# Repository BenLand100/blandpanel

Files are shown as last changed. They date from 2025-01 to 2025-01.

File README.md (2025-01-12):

# BLandPanel

This aims to be a reference design for a DYI telescope automated flat panel.
Any RP2040 dev board, or similar device, capable of running MicroPython,
a PWM modulated servo, and some commodity electronics components make up the
electronics. Some Python and C++ for writing the firmware and software driver
(respectively - which is quite ironic) to allow INDI capable clients to control
the device and a bit of CAD and 3D printing to hold it all together.

The flat panel ~~and CAD itself are~~ is TBD.

## RP2040 Firmware

Firmware for the RP2040 microcontroller is available in `rpico-firmare`.

Any RP2040 dev board with some reasonable pinout will work. This repo is tested
and configured for the vanilla Raspberry Pi Pico using some arbitrary GPIO and 
one optional-ish ADC pin. A small current driver for the LED panel will be 
required. 

## INDI driver

A driver based heavily off the reference INDI driver that can control the 
firmware is available in `indi-driver`.

## ASCOM driver

The firmware also impelemnts (untested) the flat panel serial protocol found in 
[DarkSkyGeek's ascom-flat-panel repo](https://github.com/jlecomte/ascom-flat-panel/)
so the ASCOM driver found there would very likely control this firmware fine.

## CAD Design

There is a FreeCAD project in the `design` directory along with exported models
of the current build. This is very much a WIP and the current model is a test 
design primarily to figure out what needs to be changed for the next revision.

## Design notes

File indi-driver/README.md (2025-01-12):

# BLandPanel INDI driver

For now, only implements the nost basic functionality.

```sh
mkdir build
cd build
cmake -DCMAKE_INSTALL_PREFIX=/usr -DCMAKE_BUILD_TYPE=Debug ../
make
sudo make install
```

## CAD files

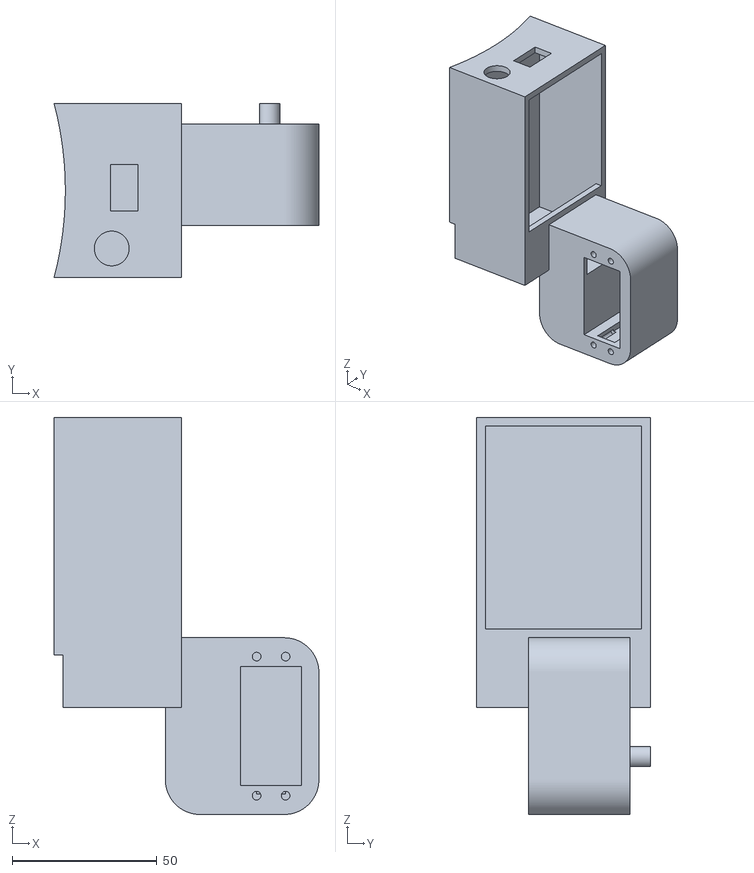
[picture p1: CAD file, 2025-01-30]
design/BlandPanel-FittedAssembly.stl
91.4 x 60.0 x 137.0

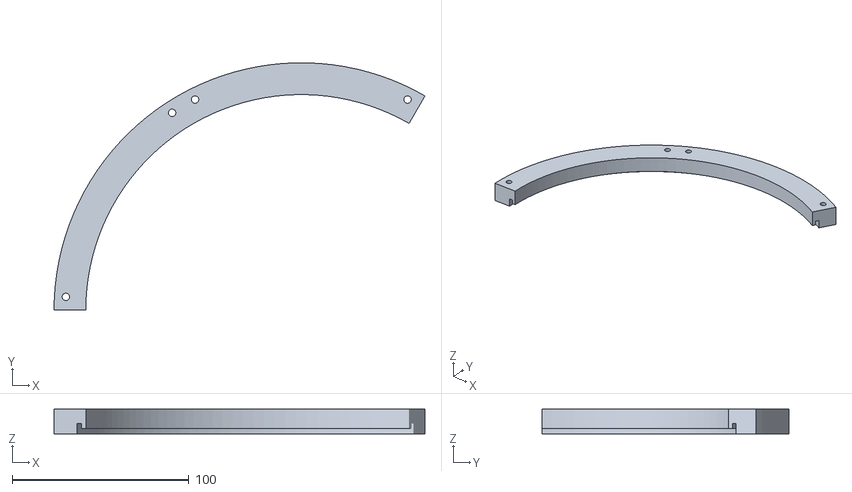
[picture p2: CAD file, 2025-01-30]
design/BlandPanel-BottomRim1.stl
210.0 x 140.0 x 14.0

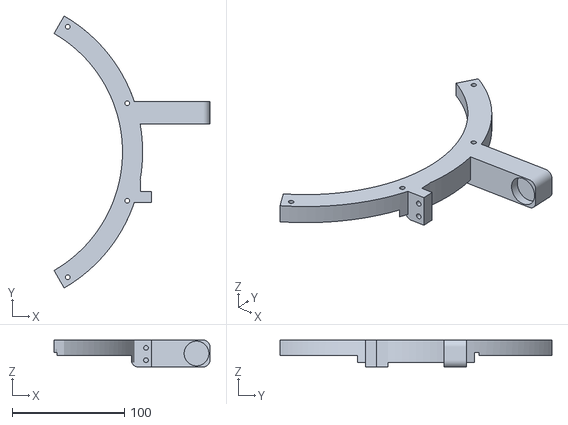
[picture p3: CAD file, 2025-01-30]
design/BlandPanel-Base.stl
139.0 x 242.5 x 24.0

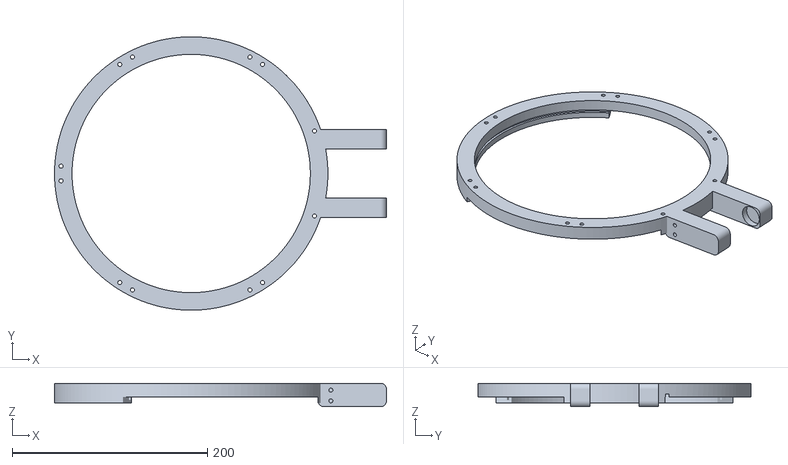
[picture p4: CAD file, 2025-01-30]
design/BlandPanel-MountablePanel.stl
340.0 x 279.9 x 24.0

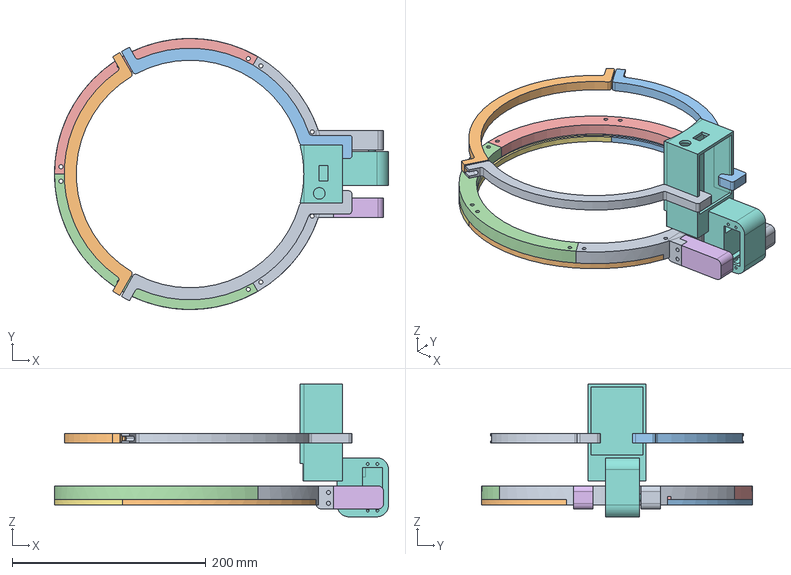
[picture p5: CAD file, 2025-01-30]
design/BlandPanel.FCStd
345.0 x 280.0 x 137.0 mm
Base
TopRim2
TopRim1
BottomRim2
BottomRim1
DriveArm
TopRim3
HousingAssembly
SideFGrabber1
SideFGrabber2
BackFGrabber

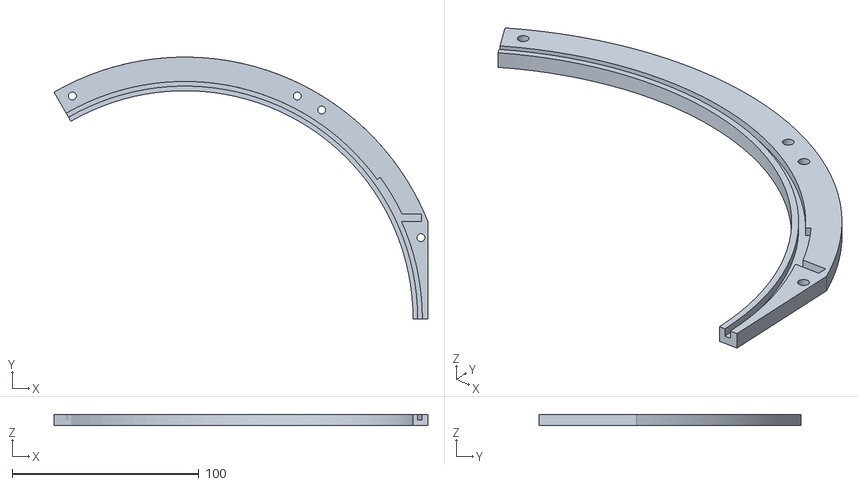
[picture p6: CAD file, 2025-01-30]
design/BlandPanel-TopRim1.stl
200.0 x 140.0 x 6.00

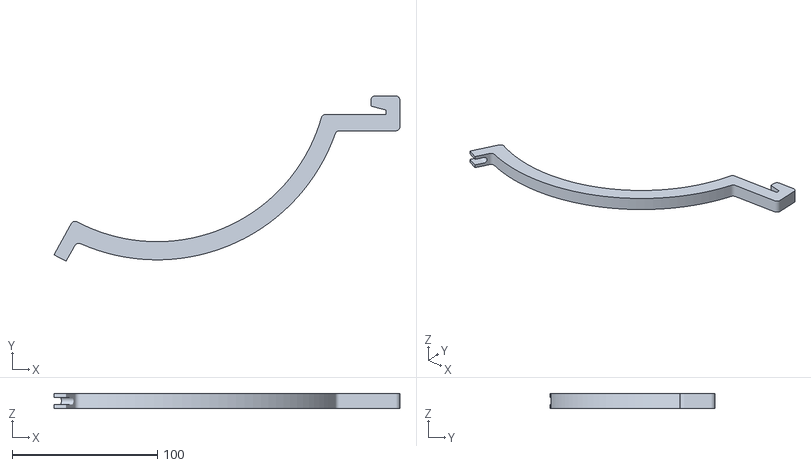
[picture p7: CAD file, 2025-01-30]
design/BlandPanel-SideGrabber.stl
237.9 x 113.6 x 10.0

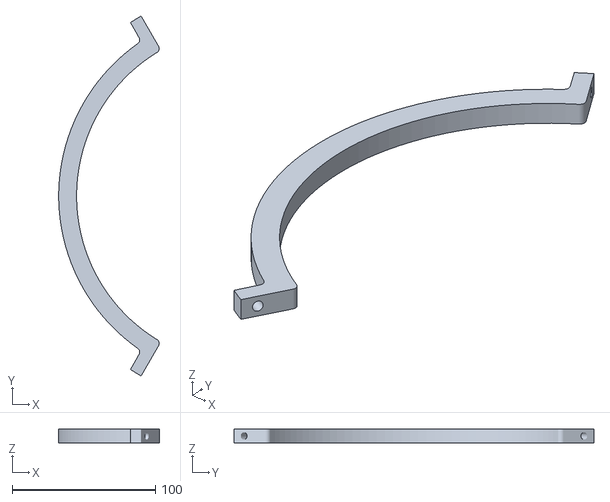
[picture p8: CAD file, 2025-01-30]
design/BlandPanel-BackGrabber.stl
70.1 x 251.1 x 10.0

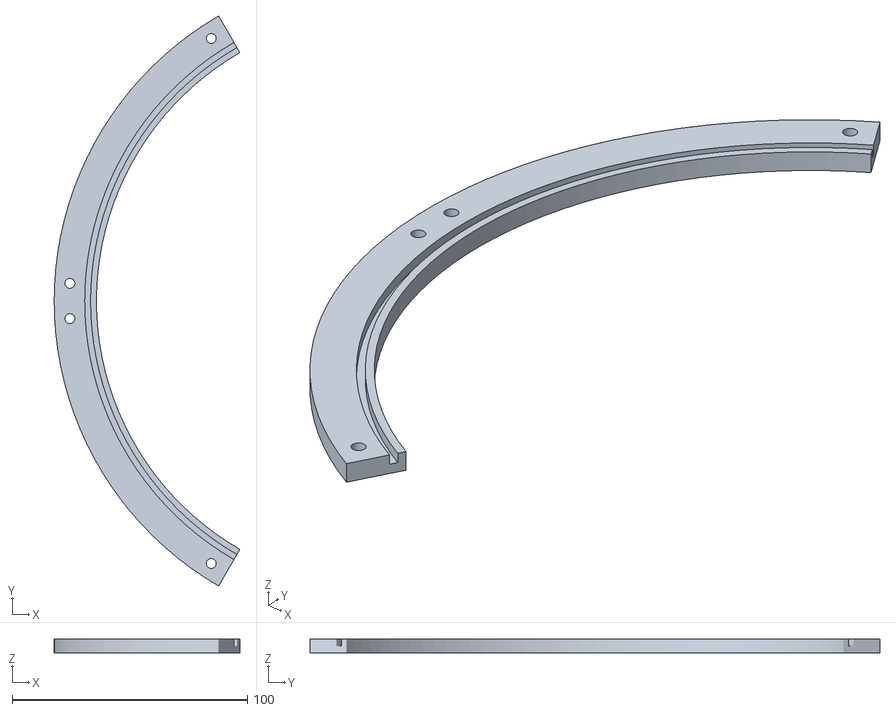
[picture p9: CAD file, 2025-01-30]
design/BlandPanel-TopRim3.stl
79.0 x 242.5 x 6.00

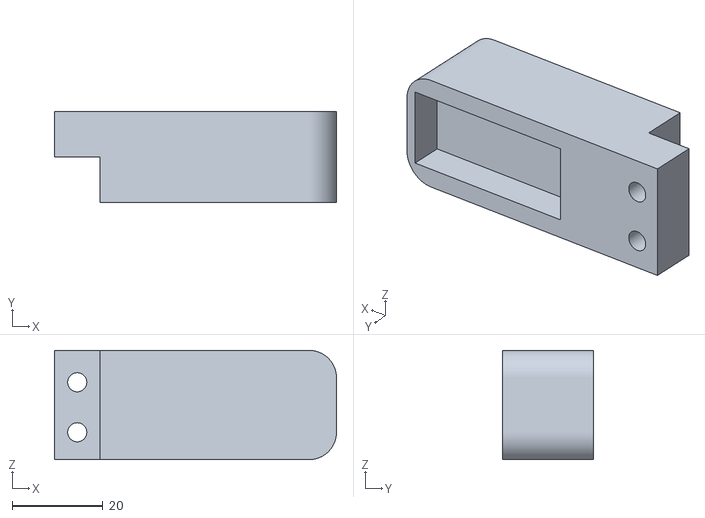
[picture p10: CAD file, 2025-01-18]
design/BlandPanel-DriveArm.stl
62.0 x 20.0 x 24.0

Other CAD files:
design/BlandPanel-BottomRim2.stl
design/BlandPanel-TopRim2.stl

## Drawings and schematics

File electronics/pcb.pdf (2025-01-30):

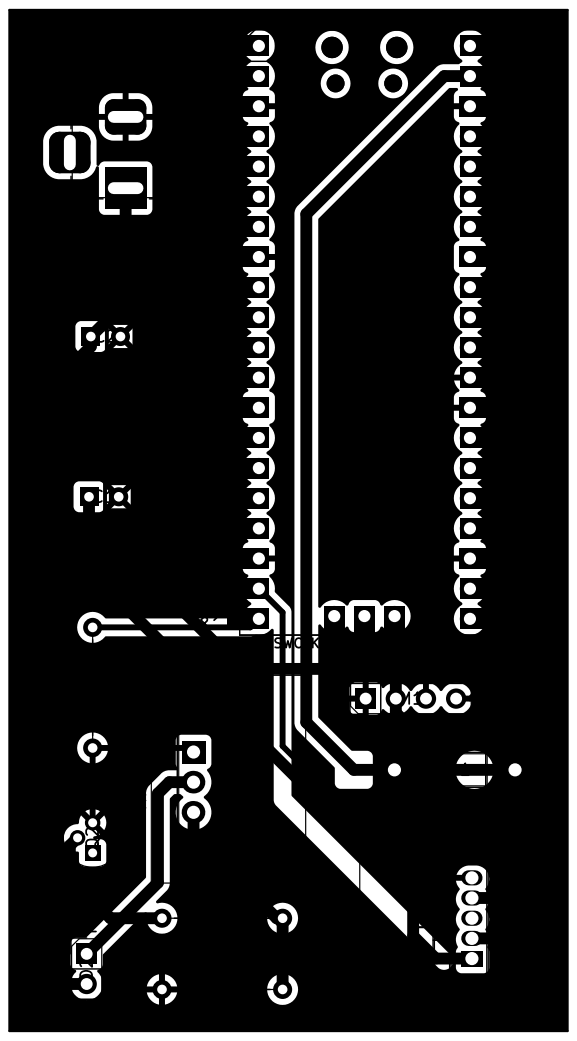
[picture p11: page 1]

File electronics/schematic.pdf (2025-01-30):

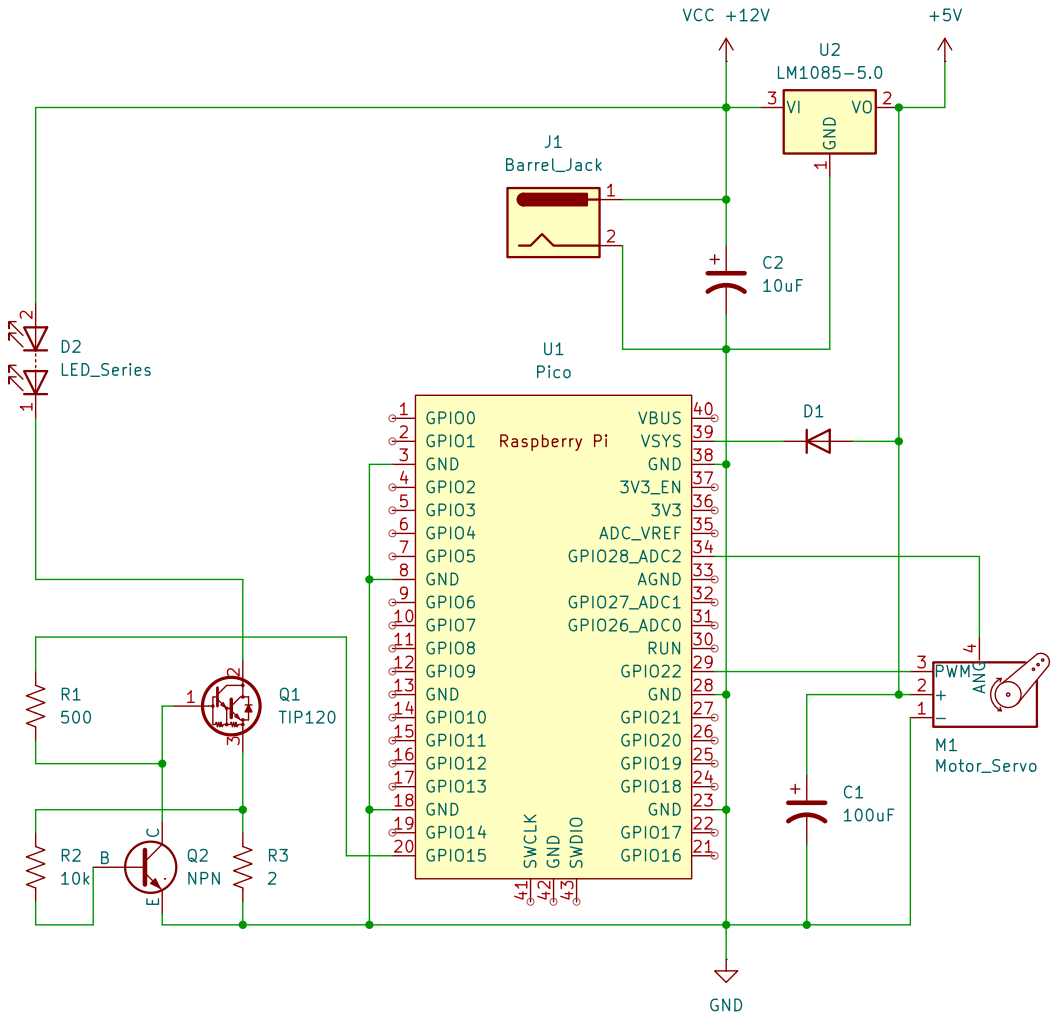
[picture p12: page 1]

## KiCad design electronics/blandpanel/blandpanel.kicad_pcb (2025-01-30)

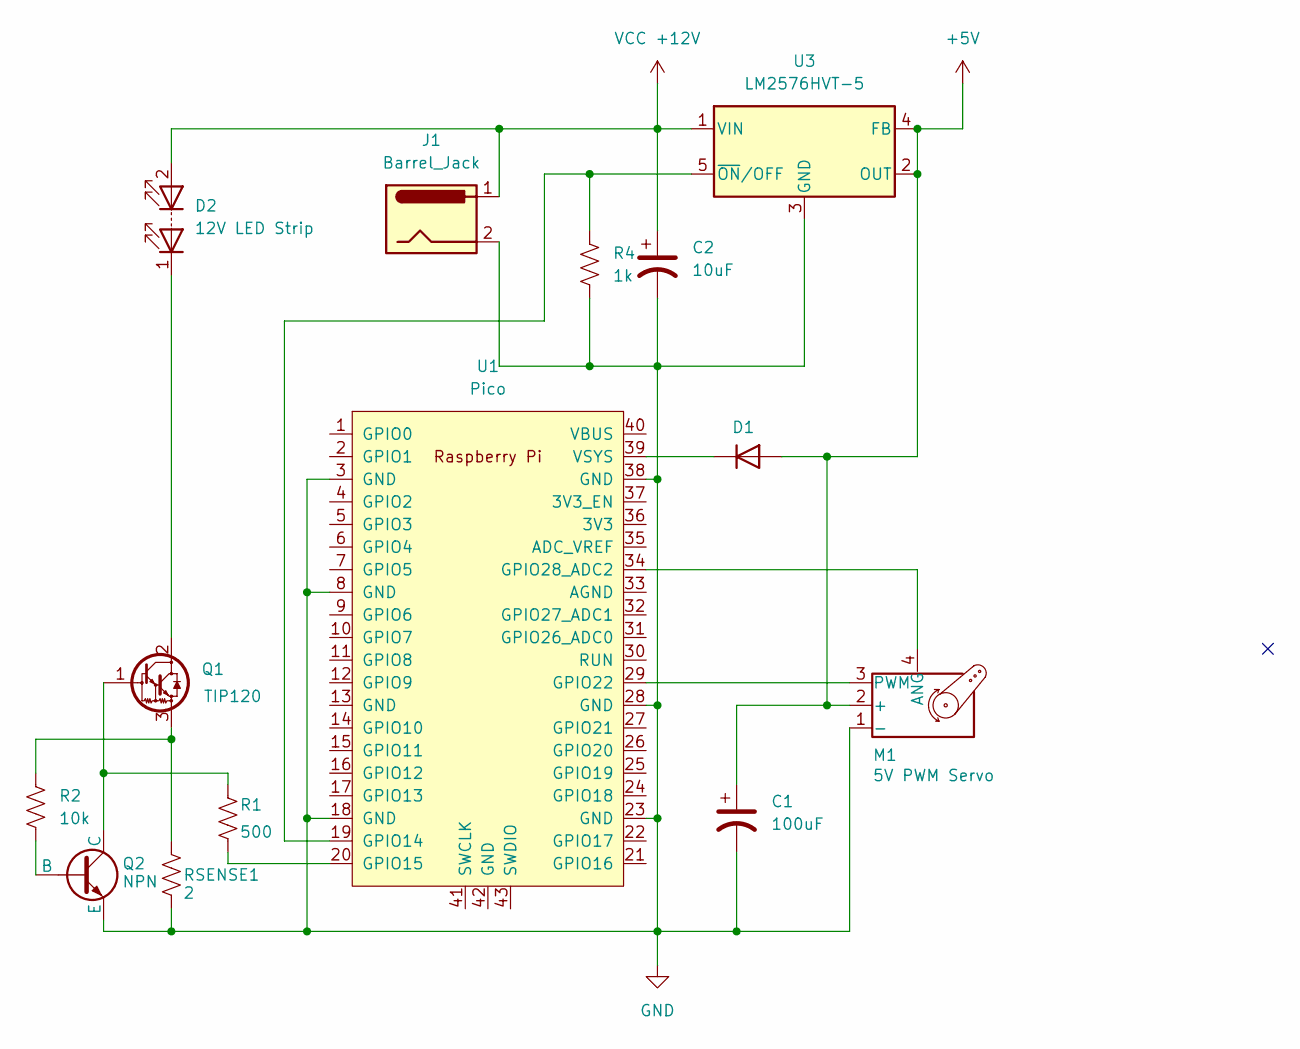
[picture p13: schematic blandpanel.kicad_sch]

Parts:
C1: 100uF; CP_Radial_D8.0mm_P2.50mm
C2: 10uF; CP_Radial_D8.0mm_P2.50mm
D1: 40V; D_DO-41_SOD81_P10.16mm_Horizontal
D2: 12V LED Strip; PinHeader_1x02_P2.54mm_Vertical
J1: Barrel_Jack; BarrelJack_Horizontal
M1: 5V PWM Servo; PinHeader_1x04_P2.54mm_Vertical
Q1: TIP120; TO-220-3_Vertical
Q2: NPN; TO-92
R1: 500; R_Axial_DIN0207_L6.3mm_D2.5mm_P10.16mm_Horizontal
R2: 10k; R_Axial_DIN0207_L6.3mm_D2.5mm_P10.16mm_Horizontal
R4: 1k
RSENSE1: 2; R_Axial_DIN0207_L6.3mm_D2.5mm_P10.16mm_Horizontal
U1: Pico; RPi_Pico_SMD_TH
U3: LM2576HVT-5; TO-220-5_Vertical

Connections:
+5V: C1.1, D1.2 (A), M1.2 (+), U3.2 (OUT), U3.4 (FB)
GND: C1.2, C2.2, J1.2, M1.1 (-), Q2.3 (E), R4.2, RSENSE1.2, U1.3 (GND), U1.8 (GND), U1.18 (GND), U1.23 (GND), U1.28 (GND), U1.38 (GND), U3.3 (GND)
unnamed: D1.1 (K), U1.39 (VSYS)
unnamed: D2.1 (K), Q1.2 (C)
unnamed: M1.4 (ANG), U1.34 (GPIO28_ADC2)
unnamed: M1.3 (PWM), U1.29 (GPIO22)
unnamed: Q1.1 (B), Q2.1 (C), R1.1
unnamed: Q1.3 (E), R2.1, RSENSE1.1
unnamed: Q2.2 (B), R2.2
unnamed: R4.1, U1.19 (GPIO14), U3.5 (~ON/OFF)
unnamed: R1.2, U1.20 (GPIO15)
VCC +12V: C2.1, D2.2 (A), J1.1, U3.1 (VIN)

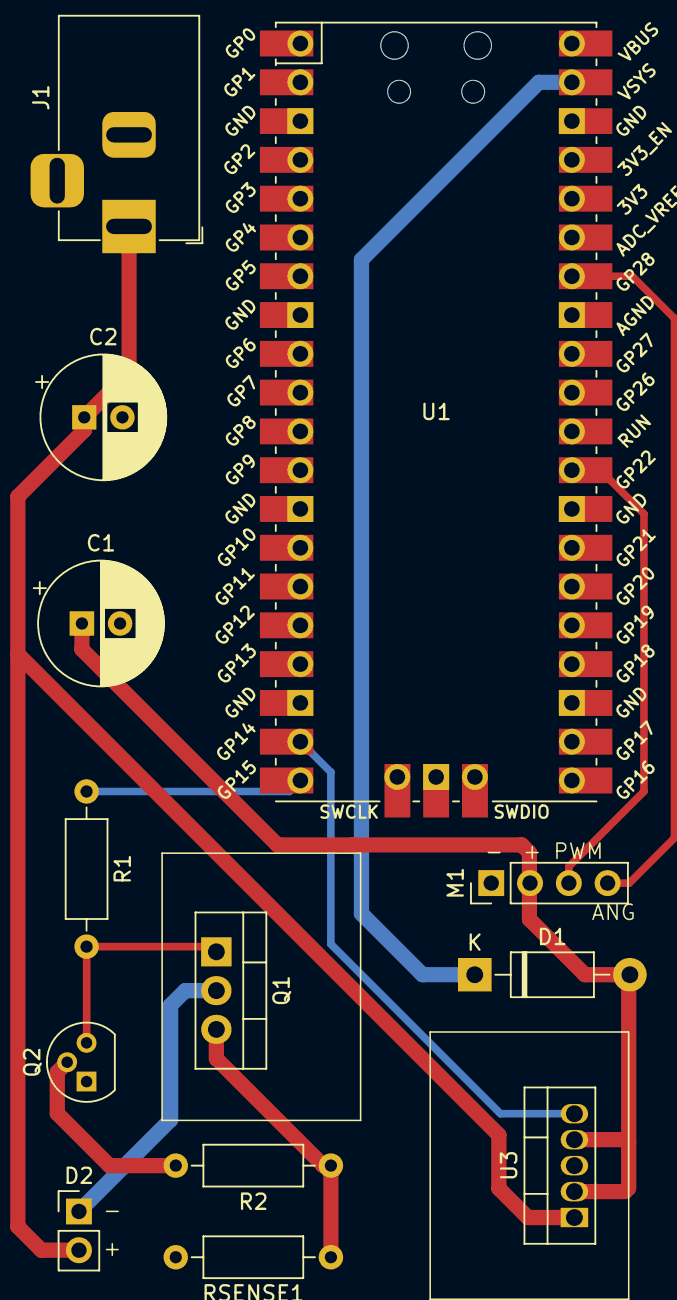
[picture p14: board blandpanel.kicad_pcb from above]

Board: 2 copper layers, 13 parts (0 on the bottom side), 12 nets.

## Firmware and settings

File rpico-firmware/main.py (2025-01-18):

import machine
import time
import sys
from machine import SoftI2C, SoftSPI, PWM, ADC, Pin

# Power LED
led = Pin(25, Pin.OUT)
led.value(1)

# PWM for flat panel
panel = PWM(Pin(15))
panel.freq(10000)
panel.duty_ns(0)

# 5V from 12V regulator (for servo & pico)
en_5v = Pin(14, Pin.OUT)
en_5v.value(0)

# PWM servo 500us - 2500us pulse range (make configurable?)
servo = PWM(Pin(22))
servo.duty_ns(0) #Servo will ignore
servo.freq(100)

# Turn on Servo and 5V bus
en_5v.value(1)

# Analog value proportional to servo angle (optional)
angle_adc = ADC(2)

# TODO save in flash?
PULSE_ZERO = -0.026
PULSE_270 = 0.951
ADC_ZERO = 60850.8
ADC_270 = 6985.0
GUID = 'some-kind-of-unique-identifier'
DEFAULT_BRIGHTNESS = 0.75
ANGLE_TOLERANCE = 10.0
OPENED_ANGLE = 270.0
CLOSED_ANGLE = 0.0

def set_angle(angle, calibrating=False, wait=2):
    if not calibrating:
        assert angle >= -20 and angle <= 290, 'Angle out of bounds'
        angle = (angle / 270)*(PULSE_270-PULSE_ZERO)+PULSE_ZERO
    servo.duty_ns(int(500e3+angle*2e6))
    time.sleep(wait)
    
def get_angle(average=10, calibrating=False):
    avg = sum([angle_adc.read_u16() for i in range(average)])/average
    if calibrating:
        return avg
    else:
        return (avg-ADC_ZERO)*270/(ADC_270-ADC_ZERO)
    
def get_state():
    angle = get_angle()
    if abs(angle-CLOSED_ANGLE) < ANGLE_TOLERANCE:
        return 'closed'
    elif abs(angle-OPENED_ANGLE) < ANGLE_TOLERANCE:
        return 'opened'
    else:
        return 'intermediate'
    
def set_state(state):
    now = get_state()
    if state == 'opened':        
        if now != 'opened':
            set_angle(OPENED_ANGLE)
    elif state == 'closed':
        if now != 'closed':
            set_angle(CLOSED_ANGLE)
    else:
        raise Exception(f'Invalid state {state}')

ENABLED = False
BRIGHTNESS = DEFAULT_BRIGHTNESS

def set_enabled(enabled=True):
    global ENABLED
    if enabled:
        panel.duty_u16(int(BRIGHTNESS*(2**16-1)))
        ENABLED = True
    else:
        panel.duty_u16(0)
        ENABLED = False
    
def get_enabled(enabled=True):
    return ENABLED

def set_brightness(brightness):
    global BRIGHTNESS
    assert brightness >= 0 and brightness <= 1.0, 'Brightness out of bounds'
    BRIGHTNESS = brightness
    if ENABLED:
        panel.duty_u16(int(BRIGHTNESS*(2**16-1)))

def get_brightness():
    return BRIGHTNESS

ESTOP = False
def estop():
    global ESTOP
    en_5v.value(0)
    ESTOP = True
    
def allclear():
    global ESTOP
    if ESTOP:
        ESTOP = False
        en_5v.value(1)
        
while True:
    cmd = sys.stdin.readline().upper().strip()
    try:
        if len(cmd) < 2:
            continue
        elif cmd.startswith('ESTOP'):
            estop()
            print('ESTOP: ALLCLEAR REQUIRED TO RESUME MOTION')
        elif cmd.startswith('ALLCLEAR'):
            allclear()
            print('OK')
        elif cmd.startswith('COMMAND:'): # Using this ASCOM driver https://github.com/jlecomte/ascom-flat-panel/
            if cmd == 'COMMAND:PING':
                print(f'RESULT:PING:OK:{GUID}')
            elif cmd == 'COMMAND:INFO':
                print('RESULT:INFO:BLandPanel v0')
            elif cmd == 'COMMAND:CALIBRATOR:GETBRIGHTNESS':
                print('RESULT:CALIBRATOR:BRIGHTNESS:{BRIGHTNESS}')
            elif cmd.startswith('COMMAND:CALIBRATOR:BRIGHTNESS:'):
                parts = cmd.split(':')
                if len(parts) > 3:
                    value = float(parts[3])
                    set_brightness(value)
            elif cmd.startswith('COMMAND:CALIBRATOR:ON'):
                set_state('closed')
                parts = cmd.split(':')
                if len(parts) > 3:
                    value = float(parts[3])
                    set_brightness(value)
                else:
                    set_brightness(DEFAULT_BRIGHTNESS)
            elif cmd == 'COMMAND:CALIBRATOR:OFF':
                set_enabled(False)
                set_state('opened')
            else:
                print('ERROR:INVALID_COMMAND')
        elif cmd == 'REPL':
            print('GOODBYE')
            break
        elif cmd == 'RESET':
            print('GOODBYE')
            machine.reset() #exits
        elif cmd == 'STATUS':
            print(f'OK STATE: {get_state().upper()} BRIGHTNESS: {get_brightness():0.2f} ENABLED: {str(get_enabled()).upper()}')
        elif cmd.startswith('ON'):
            parts = cmd.split(' ')
            if len(parts) > 1:
                value = float(parts[1])
                set_brightness(value)
            set_enabled(True)
            print('OK')
        elif cmd == 'OFF':
            set_enabled(False)
            print('OK')
        elif cmd.startswith('BRIGHT'):
            parts = cmd.split(' ')
            if len(parts) > 1:
                value = float(parts[1])
                set_brightness(value)
                print('OK')
            else:
                print(f'{get_brightness():0.2f}')
        elif cmd == 'OPEN':
            set_state('opened')
            if get_state() == 'opened':
                print('OK')
            else:
                print('FAIL')
        elif cmd == 'CLOSE':
            set_state('closed')
            if get_state() == 'closed':
                print('OK')
            else:
                print('FAIL')
        elif cmd.startswith('STATE'):
            parts = cmd.split(' ')
            if len(parts) > 1:
                state = parts[1].lower()
                set_state(state)
                if get_state() == state:
                    print('OK')
                else:
                    print('FAIL')
            else:
                print(get_state().upper())
        elif cmd.startswith('ANGLE'):
            parts = cmd.split(' ')
            if len(parts) > 1:
                value = float(parts[1])
                set_angle(value)
                angle = get_angle()
                if abs(angle-value) < ANGLE_TOLERANCE:
                    print('OK')
                else:
                    print('FAIL')
            else:
                angle = get_angle()
                print(f'{angle}')
        else:
            print(f'Useful Commands: STATUS, STATE [open|closed], ON [0-1], BRIGHT [0-1], OFF, OPEN, CLOSE, ANGLE [0-270]')
    except KeyboardInterrupt as e:
        raise
    except Exception as e:
        print(f'FAULT: {e}')

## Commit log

2025-01-12 Add CAD design
    [BlandPanel-Base.stl, BlandPanel-BottomRim1.stl, BlandPanel-BottomRim2.stl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]
2025-01-12 Fix missing cable channel for servo
    [BlandPanel-FlipperAssembly.stl, BlandPanel.FCStd]
2025-01-12 Add full design
    [BlandPanel.stl]
2025-01-13 Add estop; fix clearance issues on design.
    [BlandPanel-Base.stl, BlandPanel-BottomRim2.stl, BlandPanel-DriveArm.stl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]
2025-01-18 Add electronics and final design
    [BlandPanel-Base.stl, BlandPanel-BottomRim1.stl, BlandPanel-BottomRim2.stl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]
2025-01-30 Updates for semi-final design
    [BlandPanel-BackGrabber.stl, BlandPanel-Base.stl, BlandPanel-BottomRim1.stl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]
